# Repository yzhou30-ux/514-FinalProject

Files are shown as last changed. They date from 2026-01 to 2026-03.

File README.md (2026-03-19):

# FreshSense: Smart Food Tracking and Management System

📄 [View Final Presentation (PDF)](FreshsenseDeck.pdf)

This smart refrigerator labeling system integrates multiple individual sensor "tags" with an external magnetic display "hub." The tags automatically monitor and record the time and humidity of stored food items from the moment they are detached from the hub. This system offers a cost-effective solution for food management and improves storage tracking to reduce waste.

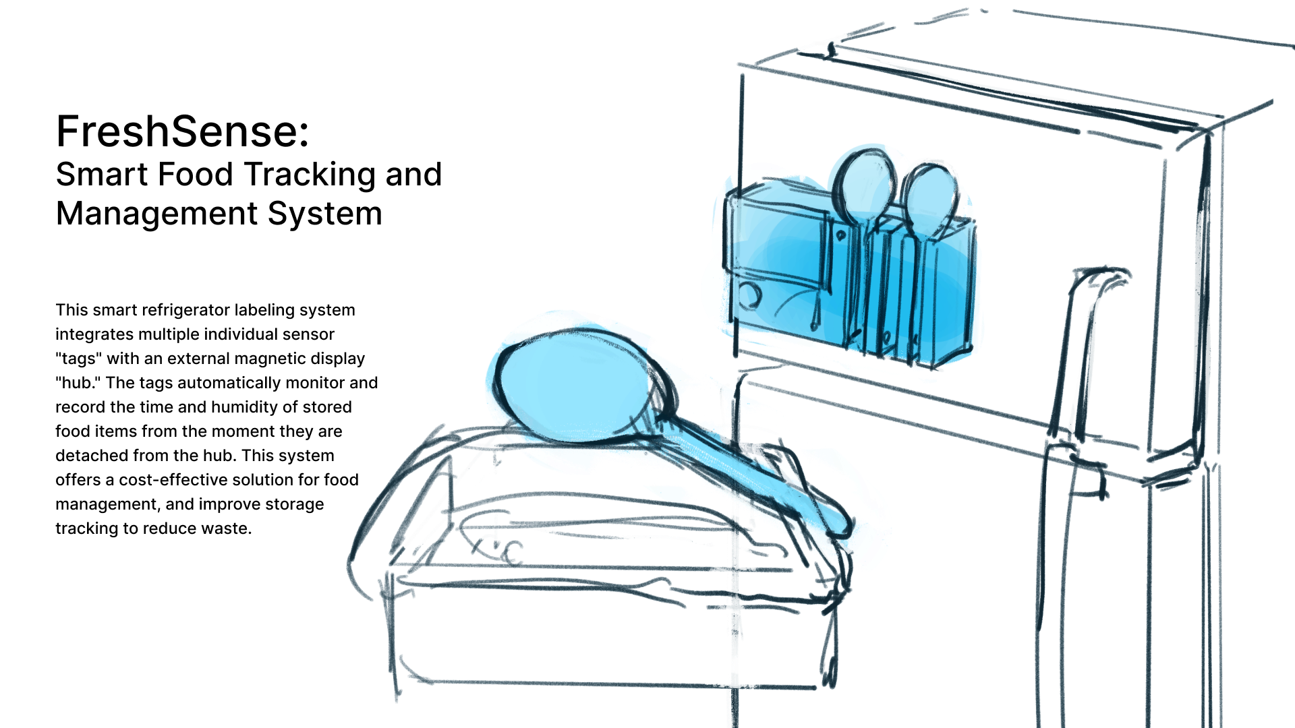
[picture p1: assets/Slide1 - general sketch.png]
general sketch


---

## TAG: Sensor

The TAG is a sensing device responsible for:
- Collecting environmental data (humidity, temperature, battery percentage, and time since detaching).
- Transmitting data to the HUB via BLE.
- Supporting contact charging for its battery.
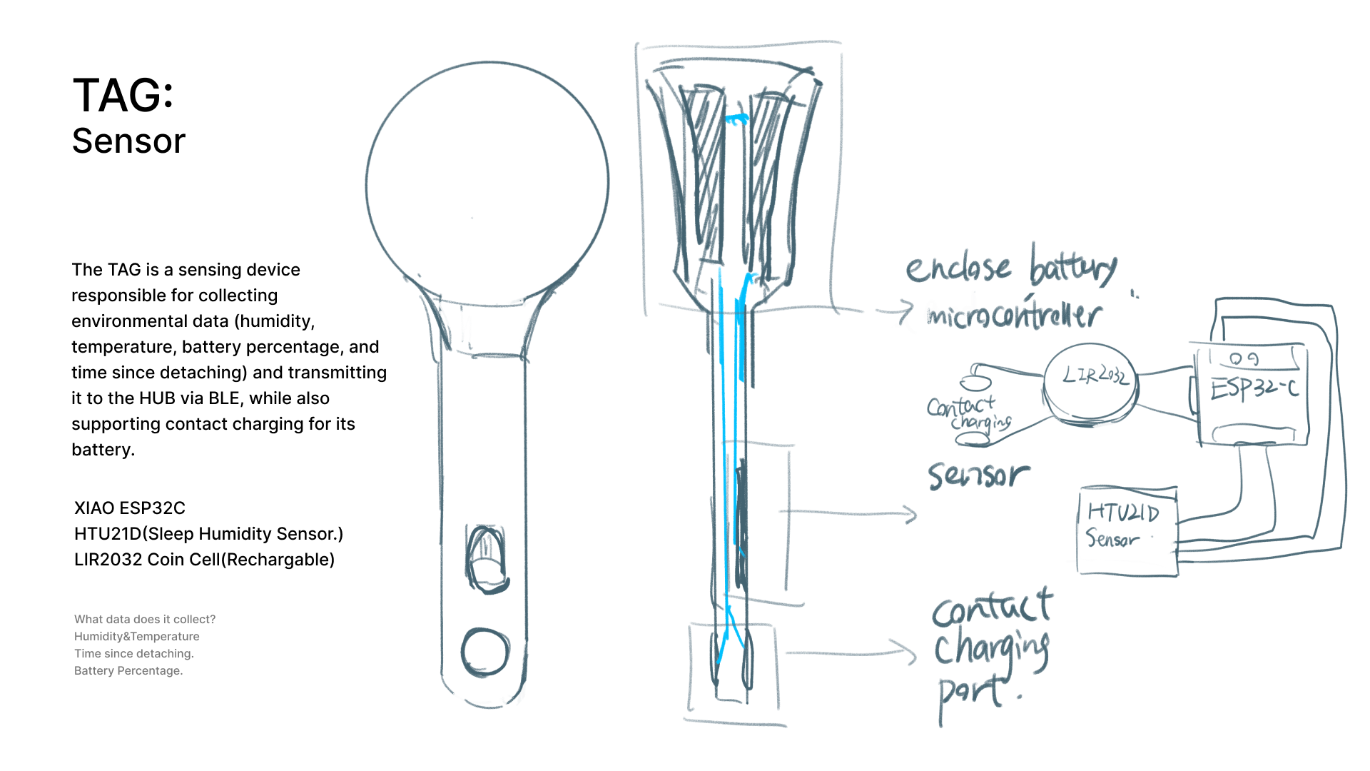
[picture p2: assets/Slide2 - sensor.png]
sensor


### Components:
- **XIAO ESP32C**
- **HTU21D** (Sleep Humidity Sensor)
- **LIR2032 Coin Cell** (Rechargeable)

### What data does the TAG collect?
- Humidity & Temperature  
- Time since detaching  
- Battery Percentage  

---

## HUB: Display

The HUB is a display controller that:
- Receives data from the TAG.
- Displays information using motor-needle, LED, and OLED interfaces.
- Manages multiple TAG addresses and states.
- Switches active TAGs.
- Monitors and displays system battery percentage.

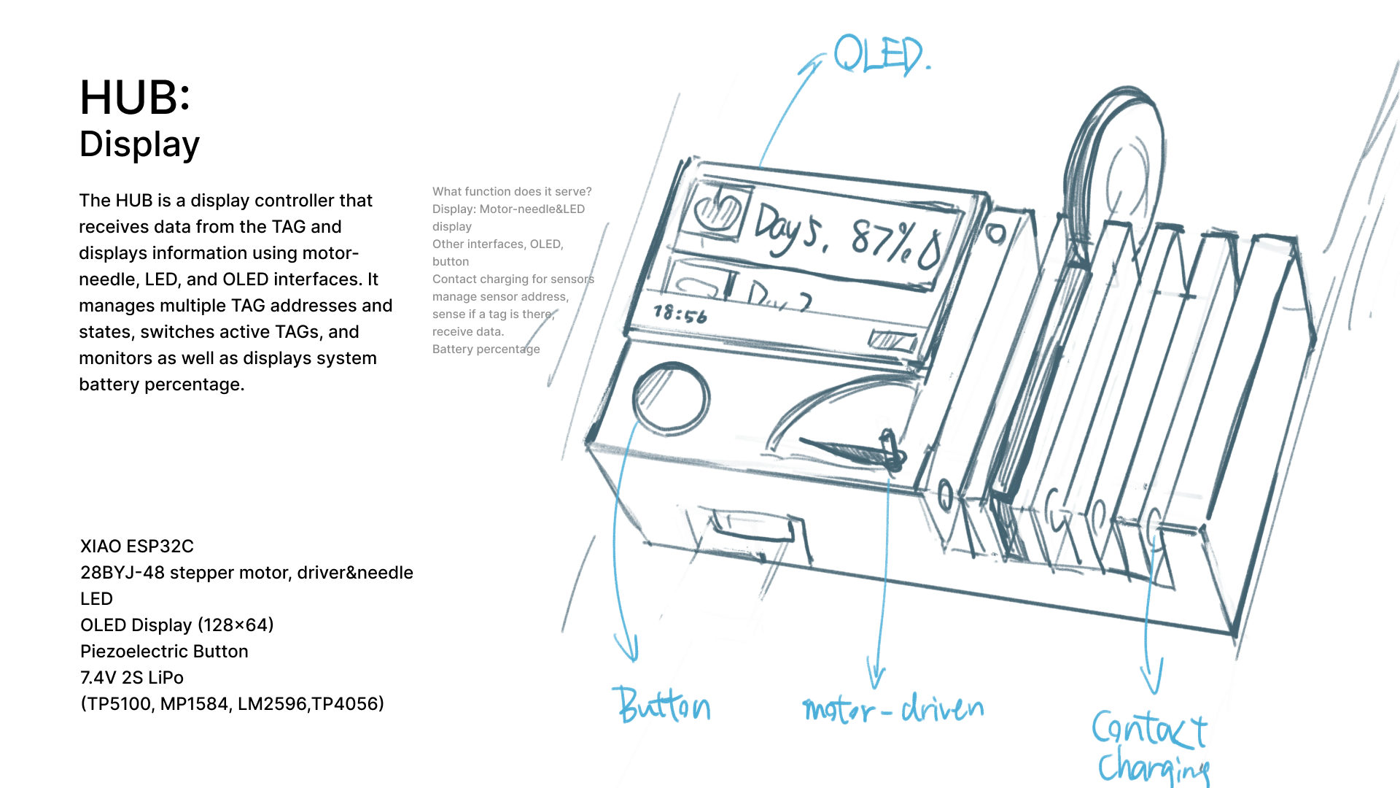
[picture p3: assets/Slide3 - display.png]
display


### Components:
- **XIAO ESP32C**  
- **28BYJ-48 Stepper Motor, Driver & Needle**  
- **LED**  
- **OLED Display** (128x64)  
- **Piezoelectric Button**  
- **7.4V 2S LiPo Battery**  
  - **TP5100**, **MP1584**, **LM2596**, **TP4056**

### What functions does the HUB serve?
- **Display**: Motor-needle and LED display.  
- **Other Interfaces**: OLED display, button.  
- **Contact Charging**: For sensors.  
- **Management**: Manage sensor addresses, detect if a TAG is present, and receive TAG data.  
- **Battery Monitoring**: Display system battery percentage.  

---

## System Communication Diagram
*(Based on BLE Communication)*
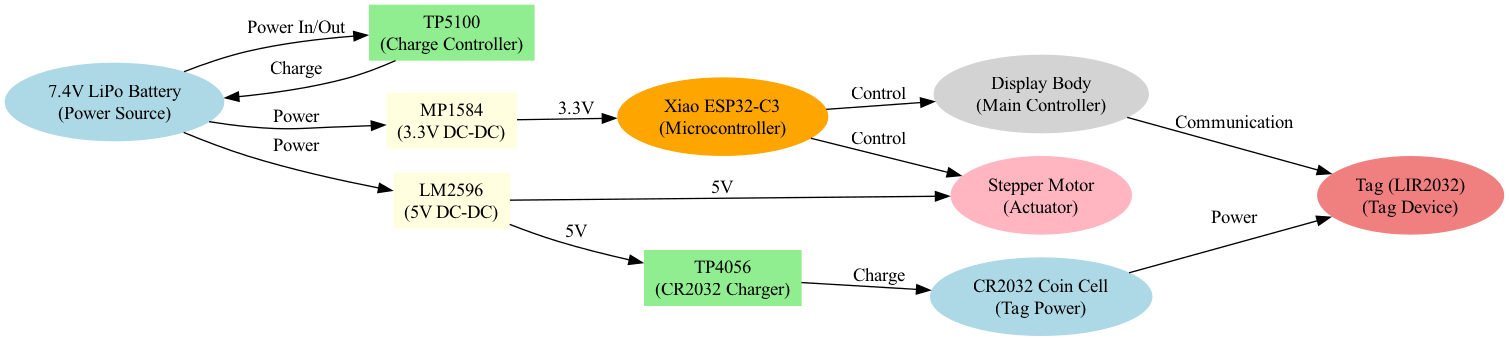
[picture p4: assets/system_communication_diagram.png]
systemcom

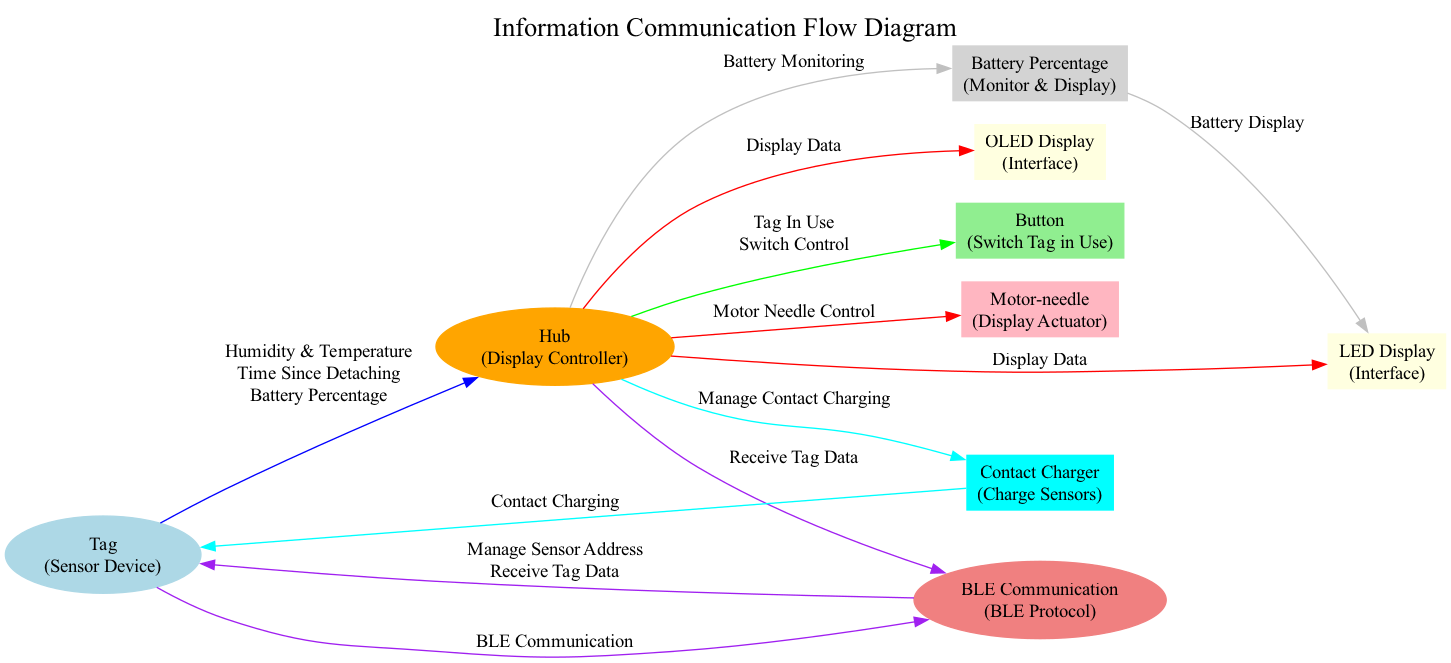
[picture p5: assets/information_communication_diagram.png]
infocom

---

## System Workflow
*(Detailed workflow of TAG and HUB interactions)*
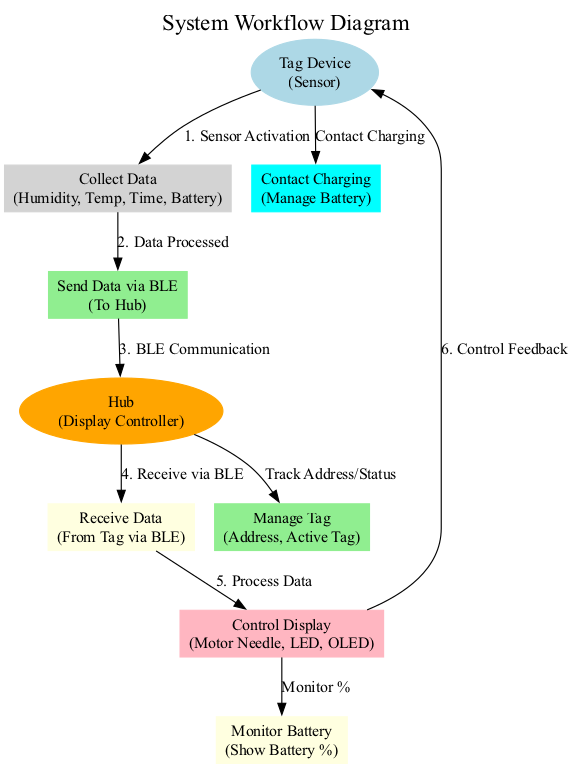
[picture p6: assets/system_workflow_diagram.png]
systemworkflow


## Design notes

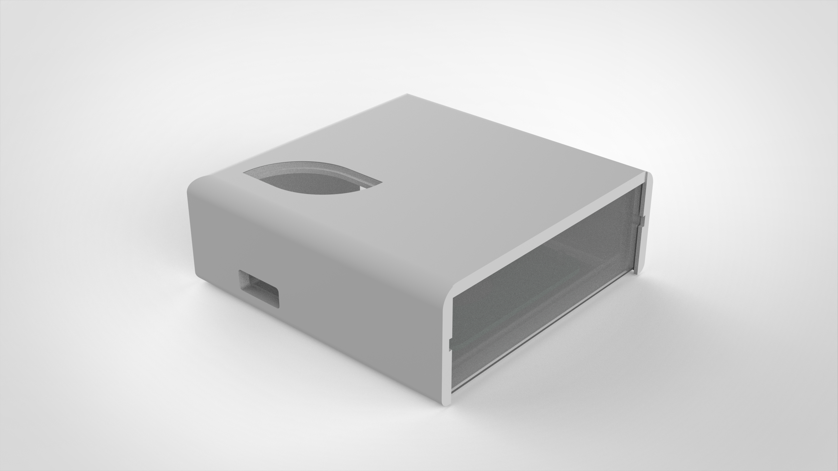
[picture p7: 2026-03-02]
enclosure/untitled.16.png

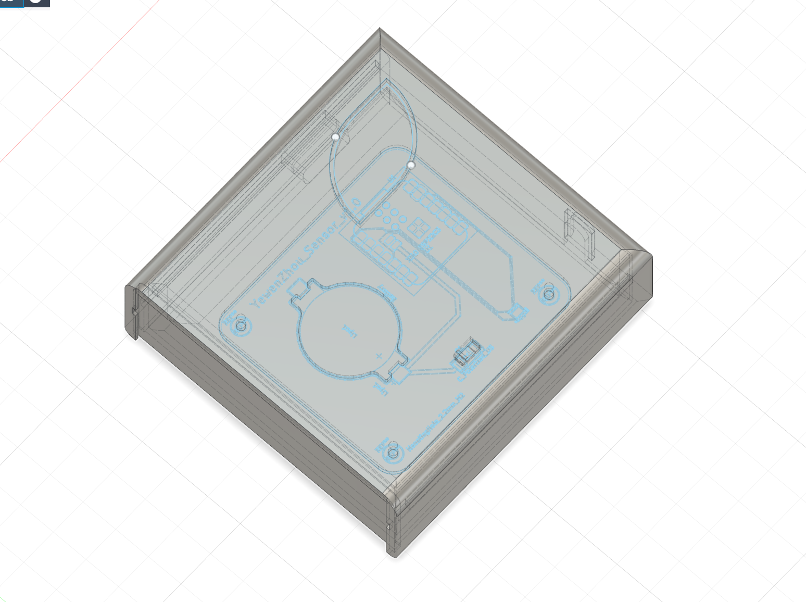
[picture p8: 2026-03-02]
enclosure/Screenshot 2026-02-20 at 6.52.20 PM.png

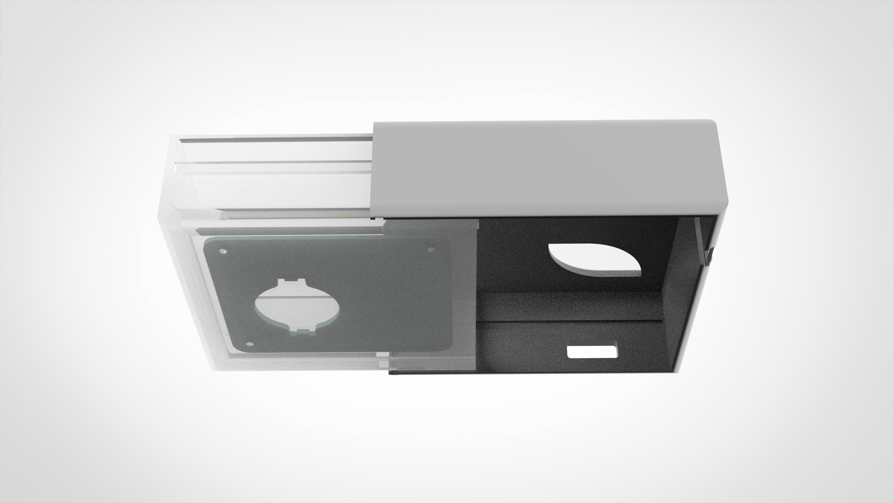
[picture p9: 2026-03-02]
enclosure/untitled.15.png

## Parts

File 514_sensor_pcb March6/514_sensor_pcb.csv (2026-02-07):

Reference | Qty | Value | DNP | Exclude from BOM | Exclude from Board | Footprint | Datasheet
C1 | 1 | C_Polarized_470uF |  |  |  | Capacitor_Tantalum_SMD:CP_EIA-6032-28_Kemet-C_HandSolder | ~
LIR2032 | 1 | Battery 3.7V |  |  |  | Battery:BatteryHolder_Keystone_1057_1x2032 | ~
U1 | 1 | XIAO ESP32C3 |  |  |  | RF_Module:MCU_Seeed_ESP32C3 | https://files.seeedstudio.com/wiki/Seeed-Studio-XIAO-ESP32/esp32-c3_datasheet.pdf
U2 | 1 | HTU21D |  |  |  | HTU21D:QFN100P300X300X100-7N

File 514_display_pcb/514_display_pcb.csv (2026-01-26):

Reference | Qty | Value | DNP | Exclude from BOM | Exclude from Board | Footprint | Datasheet
Brd? | 1 | SSD1306 |  |  |  | Display_OLED:SSD1306_I2C_128x64
D? | 1 | NeoPixel_THT |  |  |  | LED_THT:LED_WS2812B_5050 | https://www.adafruit.com/product/1938
Lipo? | 1 | Battery |  |  |  | BatteryHolder:Battery_Holder_LiPo_1S | ~
M? | 1 | Stepper_Motor_bipolar |  |  |  | Motor:Stepper_Motor_Nema17 | http://www.infineon.com/dgdl/Application-Note-TLE8110EE_driving_UniPolarStepperMotor_V1.1.pdf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
SW? | 1 | SW_Push |  |  |  | Button_Switch_THT:SW_PUSH_6mm | ~
U? | 1 | ULN2003 |  |  |  | Package_DIP:DIP-16_W7.62mm | http://www.ti.com/lit/ds/symlink/uln2003a.pdf
U? | 1 | MP1584 |  |  |  | DC_DC_Module:MP1584_Step_Down_Module
U? | 1 | LM317L_SO8 |  |  |  | Package_SO:SOIC-8_3.9x4.9mm_P1.27mm | http://www.ti.com/lit/ds/snvs775k/snvs775k.pdf
U? | 1 | XIAO ESP32C3 |  |  |  | XIAO_ESP32C3:xiao_esp32c3 | https://files.seeedstudio.com/wiki/Seeed-Studio-XIAO-ESP32/esp32-c3_datasheet.pdf

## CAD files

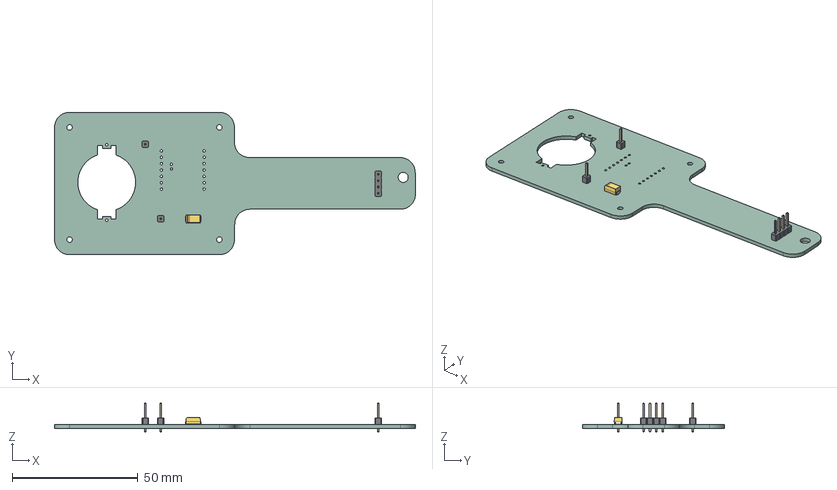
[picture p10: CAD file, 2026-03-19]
514_sensor_pcb March6/514_sensor_pcb_March6.step
143.8 x 56.7 x 11.5 mm
CP_EIA-6032-28_Kemet-C
PinHeader_1x04_P2.54mm_Vertical
PinHeader_1x01_P2.54mm_Vertical x 2
514_sensor_pcb_PCB

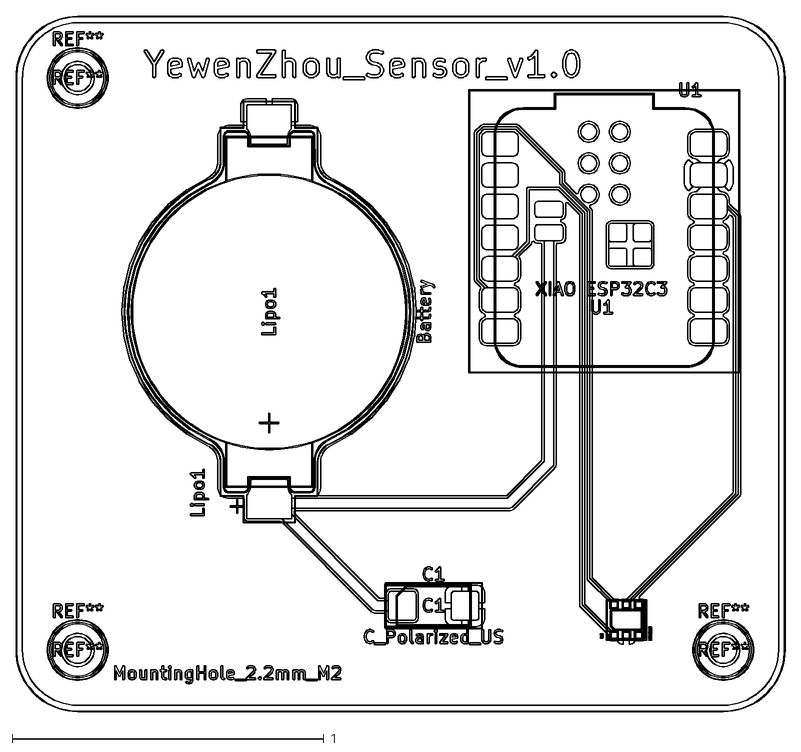
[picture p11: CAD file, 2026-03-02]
514_sensor_pcb March6/514_sensor_pcb-F_Cu.dxf
2.47 x 2.23

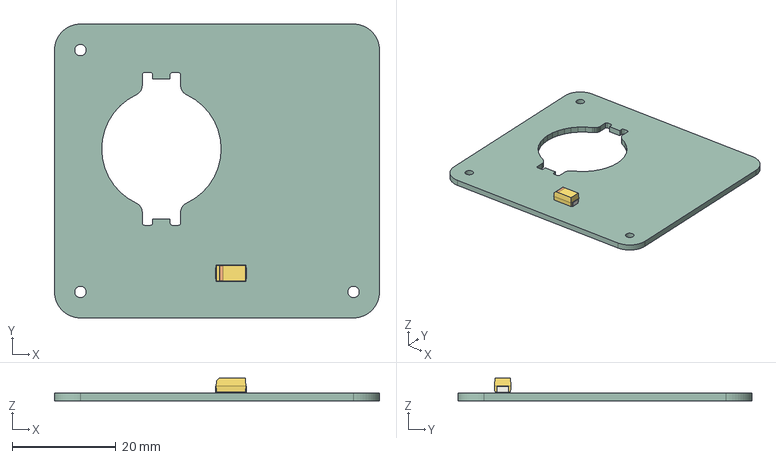
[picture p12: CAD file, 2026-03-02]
514_sensor_pcb March6/514_sensor_pcb.step
62.6 x 56.6 x 4.39 mm
CP_EIA-6032-28_Kemet-C
514_sensor_pcb_PCB

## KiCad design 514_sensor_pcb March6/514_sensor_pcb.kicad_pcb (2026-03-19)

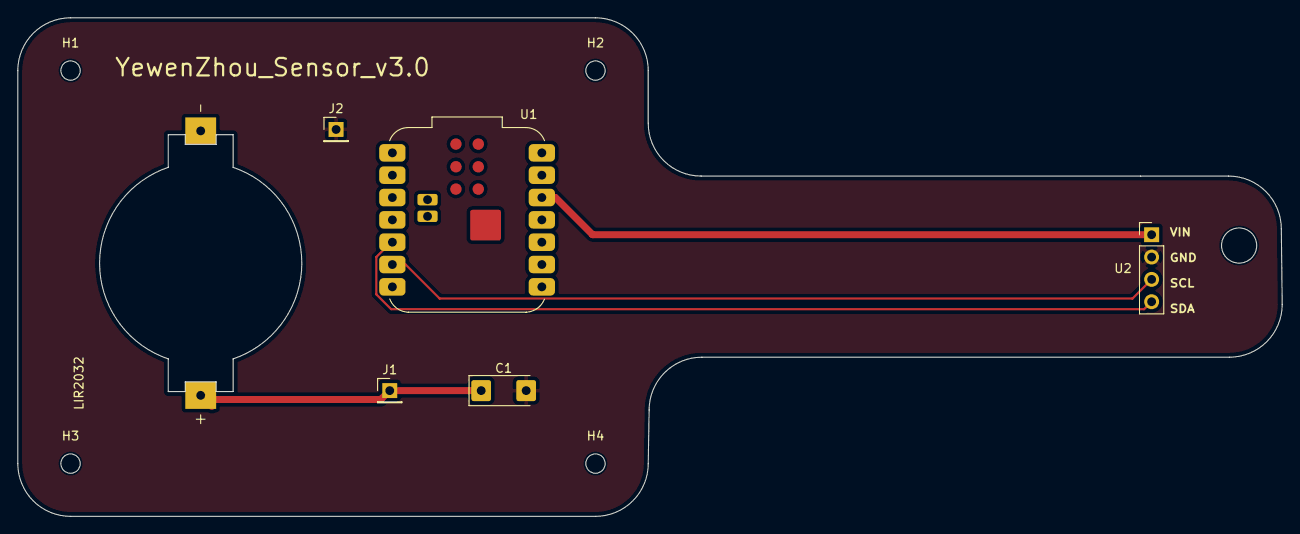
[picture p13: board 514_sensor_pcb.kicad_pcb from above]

Board: 2 copper layers, 143.8 x 56.7 mm, 10 parts (0 on the bottom side), 5 nets.

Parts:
C1: C_Polarized_470uF; CP_EIA-6032-28_Kemet-C_HandSolder
H1, H2, H3, H4: MountingHole_2.2mm_M2
J1, J2: PinHeader_1x01_P2.54mm; PinHeader_1x01_P2.54mm_Vertical
LIR2032: Battery 3.7V; BAT_1057
U1: XIAO ESP32C3; MCU_Seeed_ESP32C3
U2: HTU21D breakoutboard; PinHeader_1x04_P2.54mm_Vertical

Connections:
GND: C1.2, J2.1, U1.13 (GND), U2.2
unnamed: U1.5 (D4), U2.4
unnamed: U1.6 (D5), U2.3
unnamed: U1.12 (VCC_3V3), U2.1
VCC: C1.1, J1.1

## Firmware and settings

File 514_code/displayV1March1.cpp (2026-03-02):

#include <Arduino.h>
#include <BLEDevice.h>
#include <BLEScan.h>
#include <BLEAdvertisedDevice.h>
#include <Wire.h>
#include <Adafruit_GFX.h>
#include <Adafruit_SSD1306.h>
#include <Adafruit_NeoPixel.h>
#include <SwitecX25.h>

// ===== Pin Definitions =====
#define MOTOR_PIN1 D0
#define MOTOR_PIN2 D1
#define MOTOR_PIN3 D2
#define MOTOR_PIN4 D3
#define SDA_PIN D4
#define SCL_PIN D5
#define BUTTON_PIN D6
#define NEOPIXEL_PIN D7

// ===== Configuration =====
#define SCREEN_WIDTH 128
#define SCREEN_HEIGHT 64
#define MOTOR_STEPS 315 * 3       // X27 motor total steps
#define BLE_SCAN_TIME 5           // BLE scan duration (seconds)
#define OLED_TIMEOUT 5000         // OLED display timeout (milliseconds)
#define FRIDGE_DEVICE_NAME "FridgeSensor"  // BLE device name of fridge sensor

// ===== Humidity Range and Alarm Thresholds =====
#define HUMIDITY_MIN 50.0
#define HUMIDITY_MAX 100.0
#define HUMIDITY_ALARM_HIGH 93.0
#define HUMIDITY_ALARM_LOW 80.0

// ===== Test Mode Configuration =====
#define TEST_MODE true            // Set to false when fridge sensor is ready
#define TEST_UPDATE_INTERVAL 3000 // Test data update interval (milliseconds)

// ===== Object Initialization =====
Adafruit_SSD1306 display(SCREEN_WIDTH, SCREEN_HEIGHT, &Wire, -1);
Adafruit_NeoPixel pixel(1, NEOPIXEL_PIN, NEO_GRB + NEO_KHZ800);
SwitecX25 motor(MOTOR_STEPS, MOTOR_PIN1, MOTOR_PIN2, MOTOR_PIN3, MOTOR_PIN4);
BLEScan* pBLEScan;

// ===== State Variables =====
float temperature = 0.0;
float humidity = 0.0;
bool dataReceived = false;
unsigned long lastDataTime = 0;
unsigned long oledOnTime = 0;
bool oledActive = false;
bool lastButtonState = HIGH;

// ===== Test Mode Variables =====
unsigned long lastTestUpdate = 0;
int testStep = 0;
// Test humidity values: normal -> high alarm -> normal -> low alarm -> repeat
float testHumidityValues[] = {85.0, 88.0, 91.0, 95.0, 97.0, 90.0, 85.0, 78.0, 75.0, 70.0, 75.0, 80.0};
int testValueCount = sizeof(testHumidityValues) / sizeof(testHumidityValues[0]);

// ===== BLE Callback Class =====
class MyAdvertisedDeviceCallbacks : public BLEAdvertisedDeviceCallbacks {
  void onResult(BLEAdvertisedDevice advertisedDevice) {
    // Check if this is our fridge sensor
    if (advertisedDevice.getName() == FRIDGE_DEVICE_NAME) {
      // Parse temperature and humidity from Manufacturer Data
      if (advertisedDevice.haveManufacturerData()) {
        std::string data = advertisedDevice.getManufacturerData();
        if (data.length() >= 4) {
          // Data format: [temp_high][temp_low][humidity_high][humidity_low]
          int16_t tempRaw = ((uint8_t)data[0] << 8) | (uint8_t)data[1];
          int16_t humRaw = ((uint8_t)data[2] << 8) | (uint8_t)data[3];
          temperature = tempRaw / 100.0;
          humidity = humRaw / 100.0;
          dataReceived = true;
          lastDataTime = millis();
          
          Serial.printf("Data received - Temp: %.1f C, Humidity: %.1f%%\n", temperature, humidity);
        }
      }
    }
  }
};

// ===== Function Declarations =====
void updateMotor();
void updateLED();
void checkButton();
void showOLED();
void hideOLED();
void updateTestData();

void setup() {
  Serial.begin(115200);
  delay(1000);
  Serial.println("\n===== Fridge Humidity Gauge =====");
  
  if (TEST_MODE) {
    Serial.println("*** TEST MODE ENABLED ***");
  }

  // Initialize I2C
  Wire.begin(SDA_PIN, SCL_PIN);

  // Initialize OLED
  if (display.begin(SSD1306_SWITCHCAPVCC, 0x3C)) {
    Serial.println("OLED: OK");
    display.clearDisplay();
    display.setTextSize(1);
    display.setTextColor(SSD1306_WHITE);
    display.setCursor(0, 0);
    if (TEST_MODE) {
      display.println("TEST MODE");
      display.println("Simulating data...");
    } else {
      display.println("Waiting for");
      display.println("BLE signal...");
    }
    display.display();
  }

  // Initialize NeoPixel
  pixel.begin();
  pixel.setBrightness(50);
  pixel.setPixelColor(0, pixel.Color(0, 0, 255));  // Blue = waiting
  pixel.show();
  Serial.println("NeoPixel: OK");

  // Initialize motor and zero position
  motor.zero();
  Serial.println("Motor: OK");

  // Initialize button
  pinMode(BUTTON_PIN, INPUT_PULLUP);
  Serial.println("Button: OK");

  // Initialize BLE (only in normal mode)
  if (!TEST_MODE) {
    BLEDevice::init("HumidityGauge");
    pBLEScan = BLEDevice::getScan();
    pBLEScan->setAdvertisedDeviceCallbacks(new MyAdvertisedDeviceCallbacks());
    pBLEScan->setActiveScan(true);
    pBLEScan->setInterval(100);
    pBLEScan->setWindow(99);
    Serial.println("BLE: OK");
    Serial.println("System ready, scanning BLE...");
  } else {
    Serial.println("System ready in TEST MODE");
  }
}

void loop() {
  if (TEST_MODE) {
    // Test mode: generate simulated data
    updateTestData();
  } else {
    // Normal mode: BLE scan
    BLEScanResults results = pBLEScan->start(BLE_SCAN_TIME, false);
    pBLEScan->clearResults();
  }

  // Update outputs
  updateMotor();
  updateLED();
  checkButton();
  
  // Auto-hide OLED after timeout
  if (oledActive && (millis() - oledOnTime > OLED_TIMEOUT)) {
    hideOLED();
  }

  // Update motor position (must be called frequently)
  motor.update();
  
  // Small delay in test mode to prevent CPU hogging
  if (TEST_MODE) {
    delay(10);
  }
}

// ===== Generate Test Data =====
void updateTestData() {
  if (millis() - lastTestUpdate > TEST_UPDATE_INTERVAL) {
    lastTestUpdate = millis();
    
    // Cycle through test values
    humidity = testHumidityValues[testStep];
    temperature = -5.0 + (random(0, 50) / 10.0);  // Random temp between -5 and 0
    
    dataReceived = true;
    lastDataTime = millis();
    
    Serial.printf("[TEST] Temp: %.1f C, Humidity: %.1f%%", temperature, humidity);
    
    // Print status
    if (humidity > HUMIDITY_ALARM_HIGH) {
      Serial.println(" -> TOO HUMID!");
    } else if (humidity < HUMIDITY_ALARM_LOW) {
      Serial.println(" -> TOO DRY!");
    } else {
      Serial.println(" -> Normal");
    }
    
    // Move to next test value
    testStep = (testStep + 1) % testValueCount;
    
    // Update OLED if it's active
    if (oledActive) {
      showOLED();
    }
  }
}

// ===== Update Motor Position Based on Humidity =====
void updateMotor() {
  if (!dataReceived) return;

  // Map humidity (50-100%) to motor steps (0-MOTOR_STEPS)
  float clampedHumidity = constrain(humidity, HUMIDITY_MIN, HUMIDITY_MAX);
  int targetPosition = map(clampedHumidity * 100, HUMIDITY_MIN * 100, HUMIDITY_MAX * 100, 0, MOTOR_STEPS);
  
  motor.setPosition(targetPosition);
  motor.update();
}

// ===== Update LED Color Based on Humidity Status =====
void updateLED() {
  if (!dataReceived) {
    // Blue = waiting for connection
    pixel.setPixelColor(0, pixel.Color(0, 0, 255));
  } else if (!TEST_MODE && millis() - lastDataTime > 60000) {
    // Purple = connection lost (no data for over 1 minute)
    pixel.setPixelColor(0, pixel.Color(128, 0, 128));
  } else if (humidity > HUMIDITY_ALARM_HIGH) {
    // Red = too humid
    pixel.setPixelColor(0, pixel.Color(255, 0, 0));
  } else if (humidity < HUMIDITY_ALARM_LOW) {
    // Orange = too dry
    pixel.setPixelColor(0, pixel.Color(255, 100, 0));
  } else {
    // Green = normal
    pixel.setPixelColor(0, pixel.Color(0, 255, 0));
  }
  pixel.show();
}

// ===== Check Button State =====
void checkButton() {
  bool currentState = digitalRead(BUTTON_PIN);
  
  if (lastButtonState == HIGH && currentState == LOW) {
    // Button pressed
    if (oledActive) {
      hideOLED();
    } else {
      showOLED();
    }
    delay(50);  // Debounce
  }
  
  lastButtonState = currentState;
}

// ===== Show OLED Display =====
void showOLED() {
  oledActive = true;
  oledOnTime = millis();
  
  display.clearDisplay();
  display.setTextSize(1);
  display.setCursor(0, 0);
  
  if (!dataReceived) {
    display.println("No data yet");
    if (TEST_MODE) {
      display.println("Starting test...");
    } else {
      display.println("Scanning BLE...");
    }
  } else {
    // Title
    if (TEST_MODE) {
      display.println("== TEST MODE ==");
    } else {
      display.println("=== Fridge Status ===");
    }
    display.println();
    
    // Temperature
    display.print("Temp: ");
    display.print(temperature, 1);
    display.println(" C");
    
    // Humidity
    display.print("Humidity: ");
    display.print(humidity, 1);
    display.println(" %");
    
    display.println();
    
    // Status
    if (humidity > HUMIDITY_ALARM_HIGH) {
      display.println("!! TOO HUMID !!");
    } else if (humidity < HUMIDITY_ALARM_LOW) {
      display.println("!! TOO DRY !!");
    } else {
      display.println("Status: Normal");
    }
    
    // Last update time
    display.println();
    unsigned long ago = (millis() - lastDataTime) / 1000;
    display.print("Updated: ");
    display.print(ago);
    display.println("s ago");
  }
  
  display.display();
}

// ===== Hide OLED Display =====
void hideOLED() {
  oledActive = false;
  display.clearDisplay();
  display.display();
}

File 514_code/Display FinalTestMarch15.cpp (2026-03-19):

#include <Arduino.h>
#include <BLEDevice.h>
#include <BLEClient.h>
#include <BLEUtils.h>
#include <Wire.h>
#include <Adafruit_GFX.h>
#include <Adafruit_SSD1306.h>
#include <Adafruit_NeoPixel.h>
#include <SwitecX25.h>

// ===== Pin Definitions =====
#define MOTOR_PIN1 D0
#define MOTOR_PIN2 D1
#define MOTOR_PIN3 D2
#define MOTOR_PIN4 D3
#define SDA_PIN D4
#define SCL_PIN D5
#define BUTTON_PIN D6
#define NEOPIXEL_PIN D7

// ===== Configuration =====
#define SCREEN_WIDTH 128
#define SCREEN_HEIGHT 64
#define MOTOR_STEPS 945
#define OLED_TIMEOUT 8000

// ===== BLE UUIDs (must match sensor) =====
#define SERVICE_UUID        "4fafc201-1fb5-459e-8fcc-c5c9c331914b"
#define CHAR_TEMP_UUID      "beb5483e-36e1-4688-b7f5-ea07361b26a8"
#define CHAR_HUM_UUID       "beb5483e-36e1-4688-b7f5-ea07361b26a9"
#define CHAR_UPTIME_UUID    "beb5483e-36e1-4688-b7f5-ea07361b26aa"
#define SENSOR_NAME         "TempHum_Sensor"

// ===== Temperature Display Range =====
#define TEMP_MIN -10.0
#define TEMP_MAX 30.0

// ===== Alarm Thresholds =====
#define TEMP_ALARM_HIGH 10.0
#define TEMP_ALARM_LOW 0.0
#define HUM_ALARM_HIGH 90.0
#define HUM_ALARM_LOW 30.0

// ===== Objects =====
Adafruit_SSD1306 display(SCREEN_WIDTH, SCREEN_HEIGHT, &Wire, -1);
Adafruit_NeoPixel pixel(1, NEOPIXEL_PIN, NEO_GRB + NEO_KHZ800);
SwitecX25 motor(MOTOR_STEPS, MOTOR_PIN1, MOTOR_PIN2, MOTOR_PIN3, MOTOR_PIN4);

// ===== BLE Objects =====
BLEClient* pClient = nullptr;
BLERemoteCharacteristic* pTempChar = nullptr;
BLERemoteCharacteristic* pHumChar = nullptr;
BLERemoteCharacteristic* pUptimeChar = nullptr;
BLEAdvertisedDevice* targetDevice = nullptr;
BLEScan* pBLEScan = nullptr;

// ===== State Variables =====
float temperature = 0.0;
float humidity = 0.0;
String uptime = "";
bool tempChanging = false;
bool humChanging = false;
bool dataReceived = false;
bool deviceFound = false;
bool isConnected = false;

unsigned long lastDataTime = 0;
unsigned long oledOnTime = 0;
bool oledActive = false;
bool lastButtonState = HIGH;

// ===== Breathing LED Variables =====
uint8_t breathBrightness = 0;
int8_t breathDirection = 1;
unsigned long lastBreathUpdate = 0;
#define BREATH_INTERVAL 15
#define BREATH_MIN 5
#define BREATH_MAX 60
#define BREATH_MAX_ACTIVE 255

// ===== LED Colors =====
enum LedState { 
  LED_WAITING,      // Blue - scanning/connecting
  LED_NORMAL,       // Green - all good
  LED_TEMP_HIGH,    // Red - temperature too high
  LED_TEMP_LOW,     // Cyan - temperature too low  
  LED_HUM_HIGH,     // Red - humidity too high
  LED_HUM_LOW,      // Orange - humidity too low
  LED_CHANGING,     // Magenta - data changing
  LED_DISCONNECTED  // Purple - connection lost
};
LedState currentLedState = LED_WAITING;

// ===== Function Declarations =====
void initMotor();
void updateMotor();
void updateLED();
void updateBreathing();
void checkButton();
void showOLED();
void hideOLED();
bool connectToSensor();
void parseCharacteristicData();
void setLedColor(LedState state);
uint32_t getStateColor(LedState state);

// ===== BLE Scan Callback =====
class MyScanCallbacks : public BLEAdvertisedDeviceCallbacks {
  void onResult(BLEAdvertisedDevice advertisedDevice) {
    if (advertisedDevice.getName() == SENSOR_NAME) {
      Serial.println("Found sensor!");
      targetDevice = new BLEAdvertisedDevice(advertisedDevice);
      deviceFound = true;
      pBLEScan->stop();
    }
  }
};

// ===== BLE Client Callbacks =====
class MyClientCallbacks : public BLEClientCallbacks {
  void onConnect(BLEClient* client) {
    Serial.println("Connected to sensor");
    isConnected = true;
  }
  
  void onDisconnect(BLEClient* client) {
    Serial.println("Disconnected from sensor");
    isConnected = false;
    dataReceived = false;
  }
};

// ===== Notify Callbacks =====
void tempNotifyCallback(BLERemoteCharacteristic* pChar, uint8_t* pData, size_t length, bool isNotify) {
  String value = String((char*)pData).substring(0, length);
  
  // Parse "25.3C" or "25.3C*"
  tempChanging = value.endsWith("*");
  if (tempChanging) {
    value = value.substring(0, value.length() - 2); // Remove "C*"
  } else {
    value = value.substring(0, value.length() - 1); // Remove "C"
  }
  temperature = value.toFloat();
  dataReceived = true;
  lastDataTime = millis();
  
  Serial.printf("Temp: %.1fC %s\n", temperature, tempChanging ? "(CHANGING)" : "");
}

void humNotifyCallback(BLERemoteCharacteristic* pChar, uint8_t* pData, size_t length, bool isNotify) {
  String value = String((char*)pData).substring(0, length);
  
  // Parse "45.2%" or "45.2%*"
  humChanging = value.endsWith("*");
  if (humChanging) {
    value = value.substring(0, value.length() - 2); // Remove "%*"
  } else {
    value = value.substring(0, value.length() - 1); // Remove "%"
  }
  humidity = value.toFloat();
  
  Serial.printf("Humidity: %.1f%% %s\n", humidity, humChanging ? "(CHANGING)" : "");
}

void uptimeNotifyCallback(BLERemoteCharacteristic* pChar, uint8_t* pData, size_t length, bool isNotify) {
  uptime = String((char*)pData).substring(0, length);
  Serial.printf("Uptime: %s\n", uptime.c_str());
}

// ===== Setup =====
void setup() {
  Serial.begin(115200);
  delay(1000);
  Serial.println("\n===== Fridge Display Unit =====");

  // Initialize I2C
  Wire.begin(SDA_PIN, SCL_PIN);

  // Initialize OLED
  if (display.begin(SSD1306_SWITCHCAPVCC, 0x3C)) {
    Serial.println("OLED: OK");
    display.clearDisplay();
    display.setTextSize(1);
    display.setTextColor(SSD1306_WHITE);
    display.setCursor(0, 0);
    display.println("Initializing...");
    display.display();
  } else {
    Serial.println("OLED: FAILED");
  }

  // Initialize NeoPixel
  pixel.begin();
  pixel.setBrightness(BREATH_MIN);
  pixel.setPixelColor(0, pixel.Color(0, 0, 255));
  pixel.show();
  Serial.println("NeoPixel: OK");

  // Initialize button
  pinMode(BUTTON_PIN, INPUT_PULLUP);
  Serial.println("Button: OK");

  // Initialize motor
  initMotor();
  Serial.println("Motor: OK");

  // Initialize BLE
  BLEDevice::init("FridgeDisplay");
  pBLEScan = BLEDevice::getScan();
  pBLEScan->setAdvertisedDeviceCallbacks(new MyScanCallbacks());
  pBLEScan->setActiveScan(true);
  pBLEScan->setInterval(100);
  pBLEScan->setWindow(99);
  Serial.println("BLE: OK");

  display.clearDisplay();
  display.setCursor(0, 0);
  display.println("Scanning for");
  display.println("sensor...");
  display.display();

  Serial.println("System ready, scanning...");
}
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

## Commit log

2026-01-26 Update PCB sensor library files - Add HTU210D symbol, New_Library backup and symbol files
    [514_display_pcb.csv, 514_display_pcb.kicad_pcb, 514_display_pcb.kicad_sch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]
2026-02-07 Initial commit from workspace
    [514_display_pcb.kicad_sch, 514_sensor_pcb.csv, 514_sensor_pcb.kicad_pcb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]
2026-03-02 Update project files - Add 514_code, sensor/display PCB updates, enclosure folder, and additional resources
    [514_display_pcb.kicad_sch, 514_sensor_pcb copy.kicad_pcb, 514_sensor_pcb-F_Cu.dxf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]
2026-03-19 Update project files
    [514_sensor_pcb-F_Cu.dxf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]
